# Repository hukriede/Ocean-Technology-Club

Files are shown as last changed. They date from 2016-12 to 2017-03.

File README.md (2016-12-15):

# Ocean-Technology-Club

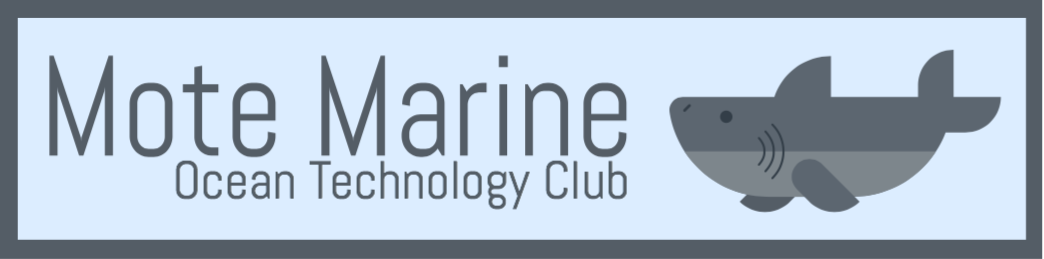
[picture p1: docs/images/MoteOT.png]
banner


> Ocean technology club is where Sarasota county high schoolers learn and apply science and technology skills through the mentorship of marine researchers at Mote.

## Table of Contents

- [Background](#background)
- [Install](#install)
- [Usage](#usage)
- [Contribute](#contribute)
- [License](#license)

## Background
OTC is a program that allows Sarasota and Manatee-county high schoolers
and teachers to learn and apply science and technology skills through the
mentorship of marine researchers at Mote.

The selected student and teacher members explore oceanography, physics,
chemistry, electronic circuitry and computer programming through real-world
examples and applications — from deploying monitoring devices in local
environments to working closely with Mote scientists using robotic gliders to
monitor for harmful algae.

## Install

```
git clone https://github.com/MoteMarine/Ocean-Technology-Club.git
```

A .pdf version of the instructions can be found in the `docs` directory. 
You can also find all of the necessary information available online in this repo's wiki.

## Usage

After building the sensor described in the documentation you'll have a fully functioning,
field-ready device. Point the Arduino to send its measurements to wherever you see fit, and
you'll be left with real-time data in an easily consumable JSON format.

## Contribute

Feel free to dive in! Open an issue or submit PRs.
We're open to all ideas and suggestions. We want to teach the best curriculum we can,
and we hope the open source community can help us do that.

## License

MIT © Mote Marine Laboratory

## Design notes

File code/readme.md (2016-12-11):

# Components

`Communicator.ino`

Asks the AboveWater Arduino to gather data and send it back. Receives the data over serial, and uses it to construct a JSON string. This string is then sent to the server via a WiFi client.

`AboveWater.ino`

Asks the BelowWater Arduino for a temperature reading on request from the Communicator ESP8266\. With this data point, and configuration variables read from the SD card it generates a line of CSV and sends it to both a file on the aforementioned SD and the Huzzah ESP8266.

`BelowWater.ino`

Takes a temperature reading on request from the AboveWater Arduino, and sends it back via serial.

`_config.txt`

Stores headers and metadata used for formatting and reporting data entries.

`SetDateTime.ino`

In order to reflect the proper date and time we can use this file a single time to set the DeadOn RTC with the current values.

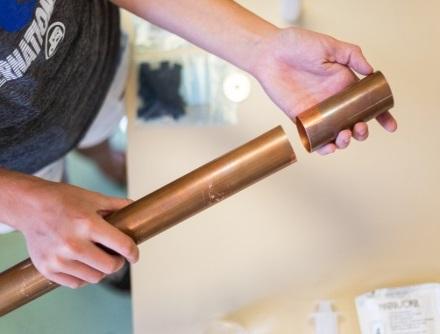
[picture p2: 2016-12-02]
docs/images/housing/cut.jpg

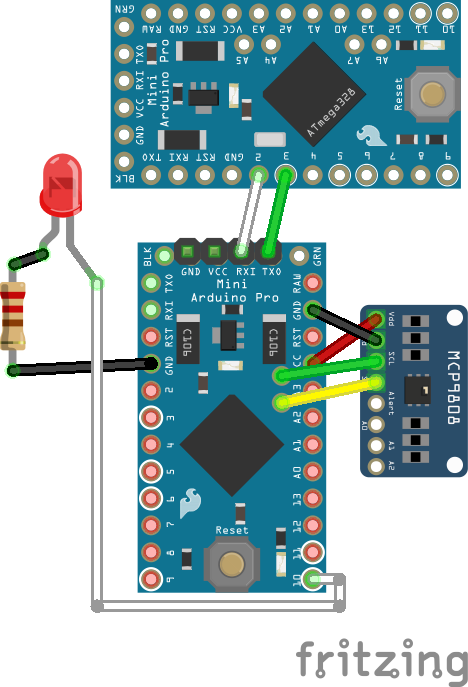
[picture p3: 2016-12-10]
docs/images/diagrams/granular/BelowDiagram_bb.png

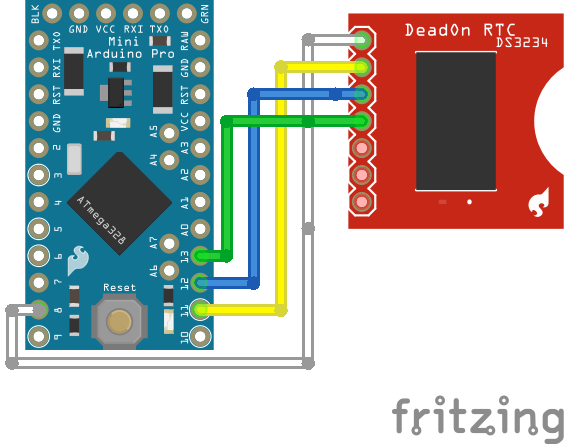
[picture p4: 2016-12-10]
docs/images/diagrams/granular/AboveDiagram.png

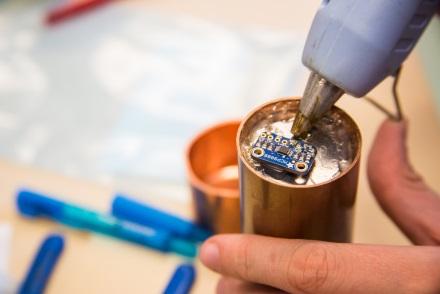
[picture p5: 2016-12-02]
docs/images/housing/epoxy.jpg

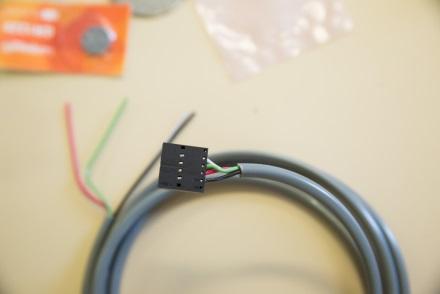
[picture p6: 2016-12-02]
docs/images/housing/insert.jpg

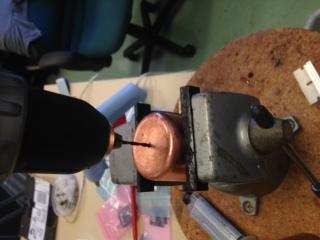
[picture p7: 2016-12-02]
docs/images/housing/drill.jpg

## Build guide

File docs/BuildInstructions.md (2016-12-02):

# Sensor Software

## Underwater Arduino

```
- Arduino IDE
    - The most recent version of the belowWater software
    - FTDI to USB cable
    - Arduino Pro Mini
    - A computer with a USB port
```

Plug the FTDI to USB cable in to your Arduino, so that when the Arduino is right-side-up, the cable has the green wire on the left and the black wire on the right.

The Arduino has BLK and GRN written next to their respective pins, so it's easy to get this arrangement right.

Open the Arduino IDE and pull up the belowWater file.

Under the "Tools" menu:

Select the "Board:" option, and change that to "Arduino Pro or Pro Mini".

Make sure that the "Processor:" says "ATmega328 (5V, 16MHz)".

Change "Port:" to whichever COM port your cable is plugged into on the computer.

Hit the upload button and you're done!

## ESP8266 Wifi Chip

```
- Arduino IDE
    - The most recent version of the ClientConnect software
    - FTDI to USB cable
    - HUZZAH ESP8266 Breakout
    - A computer with a USB port
```

Plug the FTDI to USB cable into the HUZZAH, so that when the HUZZAH is right-side-up, the cable has the green wire on the left and the black wire on the right.

Open the ClientConnect file in the Arduino IDE.

Under the "Tools" menu:

Select the "Board:" option, and change that to "Adafruit HUZZAH ESP8266"

Make sure the "CPU Frequency:" is set to 80 MHz, the "Flash size:" is set to 4M (3M SPIFFS), and "Upload speed:" is set to 115200.

Finally, make sure the "Port:" option is set to your correct COM port.

You must put the board into Bootloader mode by pressing and holding the GPIO button, pressing and releasing the reset button, then releasing the GPIO button.

The red LED above the GPIO button should be dimly lit if you did it correctly.

Press the upload button, and wait for the upload process to complete.

## Above Water Arduino

```
- Arduino IDE
  - The most recent version of the aboveWater software
  - FTDI to USB cable
  - Arduino Pro Mini
  - A computer with a USB port
```

Plug the FTDI to USB cable in to your Arduino, so that when the Arduino is right-side-up, the cable has the green wire on the left and the black wire on the right.

The Arduino has BLK and GRN written next to their respective pins, so it's easy to get this arrangement right.

Open the belowWater file in the IDE.

Under the "Tools" menu:

Select the "Board:" option, and change that to "Arduino Pro or Pro Mini".

Make sure that the "Processor:" says "ATmega328 (5V, 16MHz)".

Change "Port:" to whichever COM port your cable is plugged into on the computer.

If you're setting up the project for the first time, you'll need to program the real-time clock. To do so, refer to this segment from the README file on your microSD card (next page).

Press the upload button and wait for the upload process to complete.

## DeadOn Real Time Clock

The RTC Time is in GMT time. Currently, if you update the code it will NOT reset the clock. This is because the segment to program the clock reads:

The first line makes it so the time will only be reset if the RTC turns off or malfunctions

If you need to reset the time for any reason:

Put your computer in GMT (UTC) time to make sure the clock functions correctly

Remove the exclamation point from the inside of the if statement, so it reads

Immediately replace the exclamation point, so it looks like it originally did, and then re-upload that code. This makes the clock not reset every time the device restarts.

# Hardware

## Wiring

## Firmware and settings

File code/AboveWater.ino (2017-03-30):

#include <SparkFunDS3234RTC.h>
#include <SoftwareSerial.h>
#include <SPI.h>
#include <SD.h>

#define RTC_PIN 8
#define SD_PIN 10
SoftwareSerial BelowWaterSerial = SoftwareSerial(2, 3);

struct configs {
  int number;
  String values;
  String file;
  String date;
  String time;
};

struct configs setConfigVariables() {
  /* Creates a new configuration object to hold all necessary information

    First we open the _config.txt file on the SD card. The number of readings
    we want the BelowWater Arduino to average is collected. Then we store the
    line of CSV configuration data from the file.
  */

  struct configs currentConfigs;
  File configFile = SD.open("_config.txt");
  if (configFile) {
    while (configFile.available()) {
      currentConfigs.number = (configFile.readStringUntil(',')).toInt();
      String configVariables = configFile.readStringUntil('\n');
      configVariables.trim();
      currentConfigs.values = configVariables;
      break;
    }
    configFile.close();
  } else {
    Serial.println("error opening _config.txt");
  }
  return currentConfigs;
}

void askForTemperature(int numberOfReadings) {
  // Send the message to the BelowWater Arduino asking for the temperature

  Serial.flush();
  BelowWaterSerial.print('t');
  BelowWaterSerial.print(numberOfReadings);
  BelowWaterSerial.print('z');
  delay(500);
}

String watchForTemperatureResults() {
  // Look for results over serial waiting for the character indicating EOM

  String results;
  while (results.length() <= 0) {
    results = BelowWaterSerial.readStringUntil((char)00);
  }
  return results;
}

String createDataString(String data, struct configs* configuration) {
  /* Creates the latter portion of the string to be sent to the Huzzah

    We gather the current time, and construct a CSV string that is appended to
    the configuration, which includes date, time, and temperature.
  */
  getDateAndTime(configuration);
  String dataString = configuration->date + "," + configuration->time + "," + data + ",";
  return dataString;
}

void getDateAndTime(struct configs* configuration) {
  /* Gets the current datetime from the DeadOn and formats it appropriately

    This function is passed a reference to our configuration object. We start by updating
    the RTC's registers so that they reflect the proper time. Then we create a file name
    and two representative strings for later use.

    Setting the time on the DeadOn is required prior if we want the returned string to
    represent the correct values.
  */

  rtc.update();
  String fileName = (String(rtc.month()) + "_" + String(rtc.year()) + ".txt");
  String date = (String(rtc.month()) + "/" + String(rtc.date()) + "/" + String(rtc.year()));
  String time =  (String(rtc.hour()) + ":" + String(rtc.minute()) + ":" + String(rtc.second()));
  configuration->file = fileName;
  configuration->date = date;
  configuration->time = time;
}

void sendDataToClient(String data, String configVariables) {
  // Sends the generated CSV line to the Huzzah

  Serial.print(configVariables);
  Serial.print(data);
  Serial.print('z');
}

void writeDataToDisk(String fileName, String dataString) {
  /* Opens the appropriate file on the SD card and writes the temperature

    Using the file name we generated in the getDateAndTime function we simply
    try to open it and write a line of data if we were successful. A new file
    is used each month.
  */
  File dataFile = SD.open(fileName, FILE_WRITE);
  if (dataFile) {
    dataFile.println(dataString);
    dataFile.close();
  } else {
    Serial.print("error opening " + fileName);
  }
}

void setup() {
  Serial.begin(115200);
  BelowWaterSerial.begin(9600);
  SPI.begin();
  rtc.begin(RTC_PIN);
  while (!SD.begin(SD_PIN)) {
    Serial.println("Card failed, or not present");
  }
}

void loop() {
  /* Asks the BelowWater Arduino for the temperature when prompted.

    The AboveWater Arduino continuously waits for serial input from the Huzzah ESP8266.
    If it sees the character 'd' it gathers configuration variables from the SD card and
    asks the BelowWater Arduino for the temperature.

    Then it gets the date and time from the DeadOn RTC, writes the current temperature value
    to the SD card, and sends the gathered data (including the new temperature) to the Huzzah.
  */
  while (!Serial.available()) {
    delay(1000);
  }

  if ((char)Serial.read() == 'd') {
    struct configs configuration = setConfigVariables();
    askForTemperature(configuration.number);
    String temperature = watchForTemperatureResults();
    String data = createDataString(temperature, &configuration);
    writeDataToDisk(configuration.file, data);
    sendDataToClient(data, configuration.values);
  }
}

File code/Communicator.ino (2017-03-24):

#include <ESP8266WiFiMulti.h>
#include <ArduinoJson.h>
#include <SoftwareSerial.h>

ESP8266WiFiMulti WiFiMulti;
SoftwareSerial AboveWaterSerial(12, 14);
WiFiClient Client;

String askForData() {
  /* Grabs the temperature and configuration values from the other chips

    Asks the AboveWater Arduino for an entry of data and parses it into an array.
    The data included the temperature reading from the BelowWater Arduino.
    With this we constuct an array consumable by the JSON builder.
  */
  String dataCSV;
  AboveWaterSerial.print('d');
  while (!Serial.available()) {
    delay(1000);
  }
  dataCSV = Serial.readStringUntil('z');
  return dataCSV;
}

void splitCSV(String dataCSV, String * data) {
  /* Splits the received message into an array we use to build the JSON

    When it comes over the wire the data is in CSV form (valueA,valueB,valueC,)
    We pass this function an empty array which we can populate with the separated
    values.
  */

  char holder[dataCSV.length() + 1];
  dataCSV.toCharArray(holder, dataCSV.length() + 1);
  int counter = 0;
  int prev = 0;
  for (int i = 0; i <= dataCSV.length() + 1; i++) {
    if (holder[i] == ',') {
      data[counter] = dataCSV.substring(prev, i);
      prev = i + 1;
      counter++;
    }
  }
}

String buildJSON (String* data) {
  /* Builds the data object expected by the server

    The server expects all data to be in JSON format, so using the array we created
    with the CSV values we constuct an object including all relevant data.
  */

  StaticJsonBuffer<375> jsonBuffer;
  JsonObject& root = jsonBuffer.createObject();
  JsonObject& systems = jsonBuffer.createObject();
  JsonObject& sensors = jsonBuffer.createObject();
  JsonObject& gps = jsonBuffer.createObject();

  systems["ModelNumber"] = data[0].toInt();
  systems["SerialNumber"] = data[1].toInt();
  systems["Location"] = data[2];
  gps["Lat"] = data[3].toFloat();
  gps["Lon"] = data[4].toFloat();
  systems["Date"] = data[6];
  systems["Time"] = data[7];
  sensors["Water_Temperature"] = data[8].toFloat();

  JsonArray& System = root.createNestedArray("System");
  JsonArray& GPS = systems.createNestedArray("GPS");
  JsonArray& Sensor = root.createNestedArray("Sensors");

  System.add(systems);
  GPS.add(gps);
  Sensor.add(sensors);

  char json[350];
  root.printTo(json, sizeof(json));
  root.prettyPrintTo(Serial);
  String jsonString = json;
  jsonString.replace("[", "");
  jsonString.replace("]", "");
  return jsonString;
}

boolean connectedToHost() {
  // Attempts to make a connection with the server we'll send our data

  const char * host = "clouddev.mote.org";
  const uint16_t port = 4001;
  while (!Client.connect(host, port)) {
    delay(5000);
    Serial.print(".");
  }
  return true;
}

void sendToClient(String data) {
  // Sends the data we constructed to the server

  Serial.println(data);
  Client.print(data);
}

void setup() {
  Serial.begin(115200);
  AboveWaterSerial.begin(115200);
  WiFiMulti.addAP("", "");
  while (WiFiMulti.run() != WL_CONNECTED) {
    Serial.print(".");
    delay(500);
  }
  Serial.println("WiFi Connected");
}

void loop() {
  /* Gathers the temperature and metadata and sends it to the server.

    We ask the AboveWater Arduino for data, which ultimately results in a CSV
    message being sent over serial. That string is separated into an array, which
    is used to create a JSON object. Once constructed we send that JSON to the
    server and delay the set amount of time.
  */

  if (connectedToHost()) {
    String rawData = askForData();
    String data[10];
    splitCSV(rawData, data);
    String json = buildJSON(data);
    sendToClient(json);
    Client.stop();
    float time = data[5].toFloat() * 60 * 1000;
    delay(time);
  }
}

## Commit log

2016-11-07 Adding code and schematics
    [_config.txt, sensorsdiagram.fzz]
2016-11-07 Naming adjustments
    [_config.txt]
2016-11-10 Stripping it all down to the bare minimum
    [_config.txt]
2016-12-02 Adding markdown and pdf versions of the instructions
    [SensorsDiagram.fzz, _config.txt]
2016-12-02 Adding all images
    [SensorsDiagram.fzz]
2016-12-02 Modifies src descriptions
    [_config.txt]
2016-12-04 Should prevent SD card errors from ruining data
    [BelowWater.ino]
2016-12-07 Targeted diagrams
    [AboveDiagram.fzz, AboveSdDiagram.fzz, BelowDiagram.fzz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]
2016-12-09 Includes updated schematics
    [AboveDiagram.fzz, AboveSdDiagram.fzz, BelowDiagram.fzz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]
2016-12-10 Updating schematics
    [AboveDiagram.fzz, AboveSdDiagram.fzz, BelowDiagram.fzz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]
2016-12-15 Adds file to configure SD card via Arduino
2016-12-15 Fully documented and in working order -- some communication could still be cleaned up
    [_config.txt]
2017-01-31 Conforming to Platform.io structure
    [SensorsDiagram.fzz]
2017-02-22 Simpler folder structure
    [enclosure.fzz]
2017-03-24 Aiming to fix serial issue with a timeout if not available
    [AboveWater.ino]
